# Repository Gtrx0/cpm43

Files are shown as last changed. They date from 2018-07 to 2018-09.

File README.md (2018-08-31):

# CPM43
40% Mechanical keyboard PCB

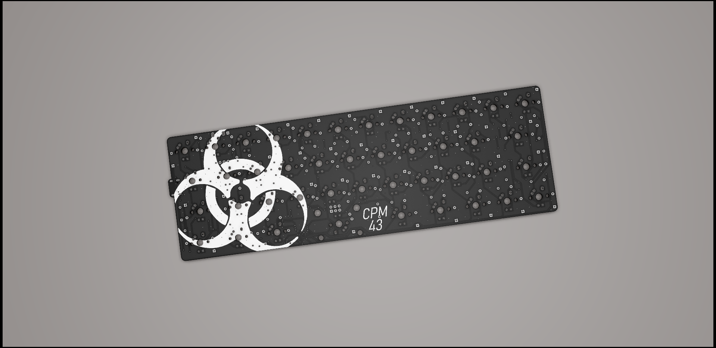
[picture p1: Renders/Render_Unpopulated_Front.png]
Frontside Render

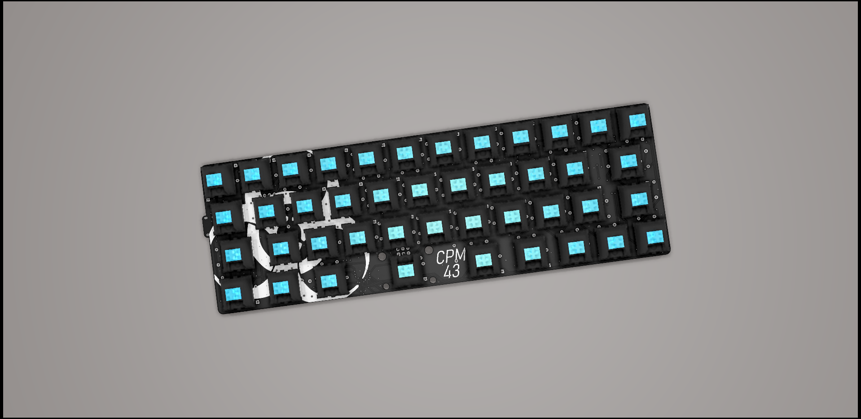
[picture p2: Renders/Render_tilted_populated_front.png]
Frontside Render

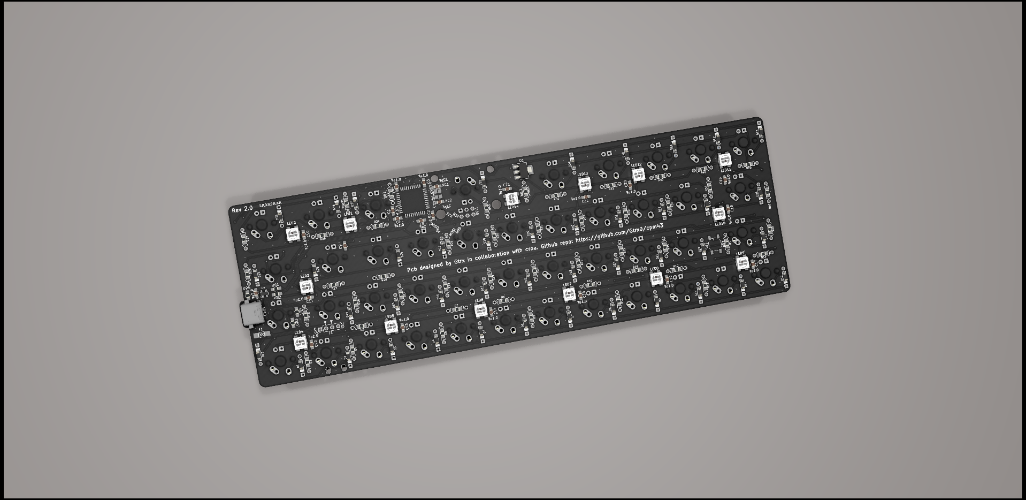
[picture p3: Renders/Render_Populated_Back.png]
Frontside Render

# [Layout](http://www.keyboard-layout-editor.com/#/gists/e3d0a9a1f7fb6537a82bb3f0c82ddf35)

## Features
* In-switch LED support.
* Individually addressible RGB underglow provided by 14 separate WS2812B LEDs.
* USB Type-C connector on the left side.
* Compatible with Cherry MX and ALPS switches. 
* Integrated 16MHz Atmega32u4 microcontroller for better QMK compatibility.
* USB ESD protection circuit.
* ICSP programming header just in case you try something a bit too extreme and need to unbrick it.
* 0805 SMD and through hole Diode/resistor compatibility for ease of assembly.
* USB breakout for extra redundency.

## Warning
KiCad 5 or above is needed to open this project. KiCad 4 or below won't work.

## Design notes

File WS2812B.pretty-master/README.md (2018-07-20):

WS2812B.pretty
==============

LAYOUT FILES: KiCad footprints for WS2812B LEDs (and pin-compatible ones).

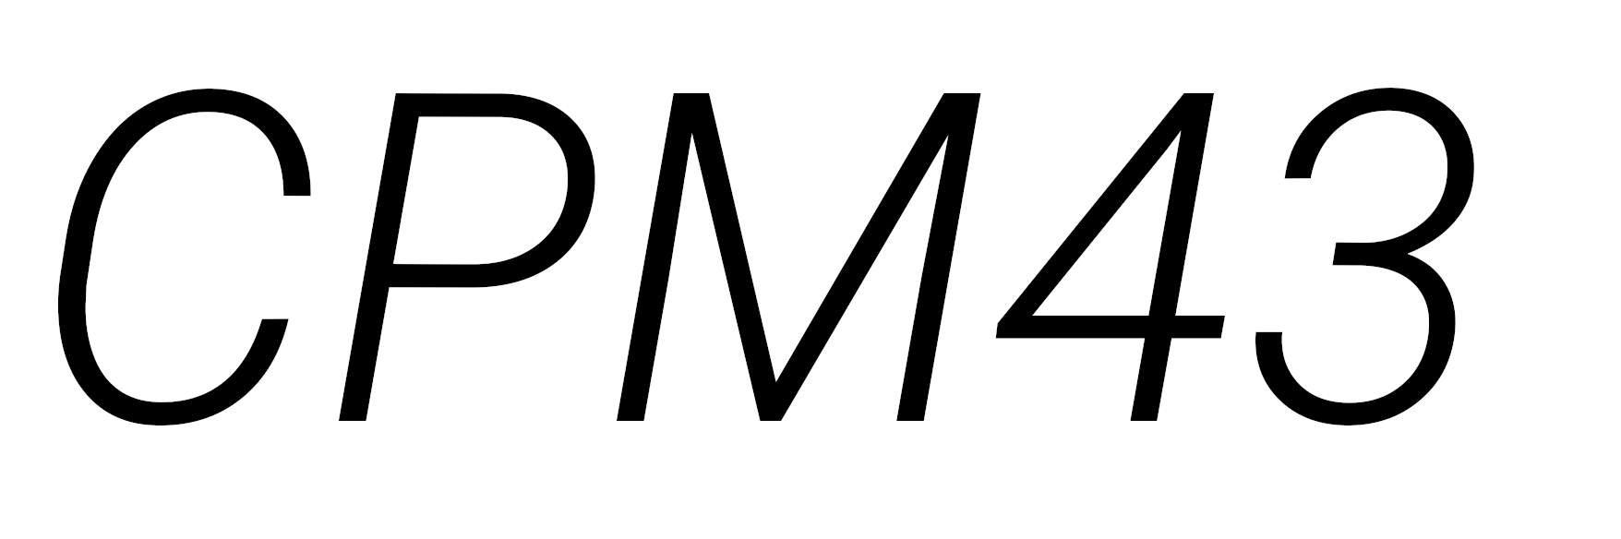
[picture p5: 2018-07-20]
CPM title/CPMtitle2.png

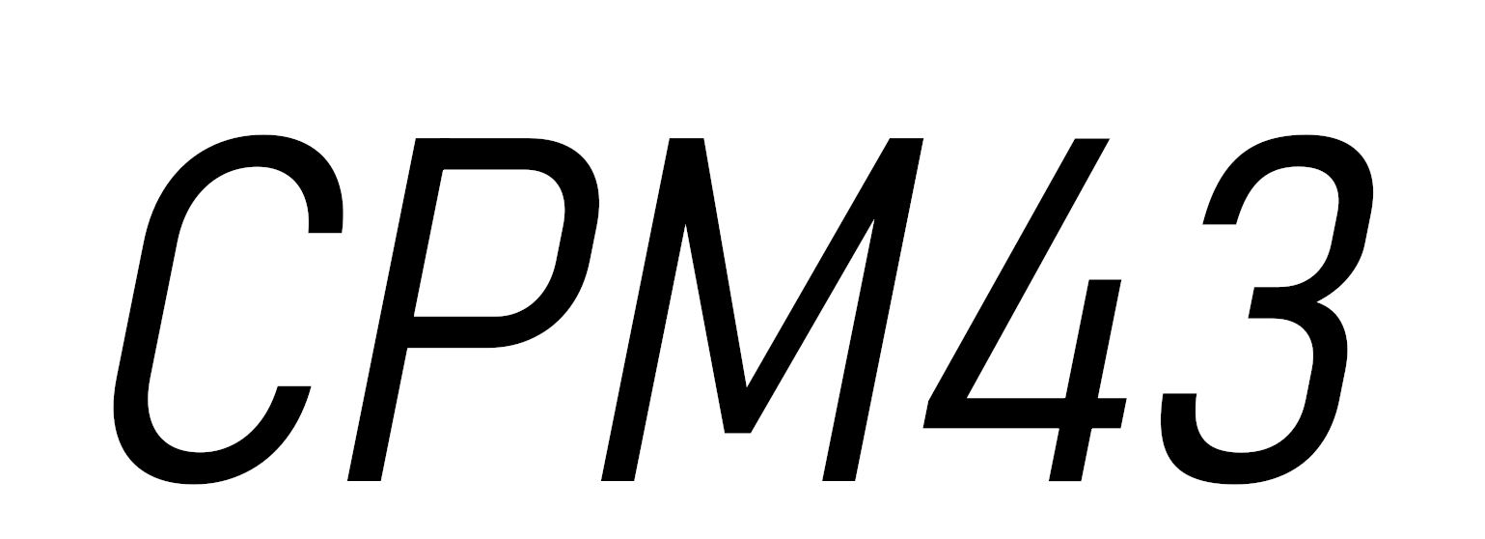
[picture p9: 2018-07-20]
CPM title/CPM4.3.png

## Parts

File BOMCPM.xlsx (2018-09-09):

Components for 1 board:
Item | Qty | Reference(s) | Value | Part name | Footprint | SMD | THT
1 | 20 | C2, C3, C4, C5, C8, C9, C10, C11, C12, C13, C14, C15, C16, C17, C18, C19, C20, C21, C22, | 0.1uF | Ceramic Capacitor | 0805_SMD | https://lcsc.com/product-detail/Multilayer-Ceramic-Capacitors-MLCC-SMD-SMT_100nF-104-5-50V_C29926.html
2 | 2 | C1, C7 | 4.7uF | Ceramic Capacitor | 0805_SMD | https://lcsc.com/product-detail/Multilayer-Ceramic-Capacitors-MLCC-SMD-SMT_SAMSUNG_CL21A475KOFNNNE_4-7uF-475-10-16V_C1746.html
3 | 1 | C6 | 1uF | Ceramic Capacitor | 0805_SMD | https://lcsc.com/product-detail/Multilayer-Ceramic-Capacitors-MLCC-SMD-SMT_KEMET_C0805C105J4RAC7800_KEMET-C0805C105J4RAC7800_C141130.html
4 | 43 | D1-43 | - | Zener Diode | THT, 0805_SMD, SOT123_SMD | https://lcsc.com/product-detail/Switching-Diode_DIODES_1N4148W-7-F_1N4148W-7-F_C83528.html | https://lcsc.com/product-detail/Switching-Diode_1N4148_C179504.html
5 | 1 | F1 | 500mA Hold | Polyfuse | 1206_SMD | https://lcsc.com/product-detail/Surface-Mount-Fuses_Littelfuse_RF1347-000_Littelfuse-RF1347-000_C207193.html
6 | 14 | LED1-14 | - | WS2812B rgb led | WS2812B_SMD | https://lcsc.com/product-detail/Light-Emitting-Diodes-LED_5050-RGBIntegrated-Light-4Pin_C114586.html
7 | 1 | NPNR1 | 1.5k ohm | Resistor | THT, 0805_SMD | https://lcsc.com/product-detail/Chip-Resistor-Surface-Mount-UniOhm_Uniroyal-Elec-0805W8J0152T5E_C26015.html | https://lcsc.com/product-detail/Metal-Film-Resistor-TH_TA-I-Tech-RN16T21501F_C172500.html
8 | 1 | Q1 | - | NPN transistor | SOT223_SMD | https://lcsc.com/product-detail/Others_Nexperia_BCP56-10-115_Nexperia-BCP56-10-115_C192156.html
9 | 2 | R1, R2 | 10k ohm | Resistor | THT, 0805_SMD | https://lcsc.com/product-detail/Chip-Resistor-Surface-Mount-UniOhm_Uniroyal-Elec-0805W8F1002T5E_C17414.html | https://lcsc.com/product-detail/Metal-Film-Resistor-TH_10KR-1002-1_C58673.html
10 | 43 | R3, R4, R5, R6, R7, R8, R9, R10, R11, R12, R13, R14, R15, R16, R17, R18, R19, R20, R21, R22, R23, R24, R25, R26, R27, R28, R29, R30, R31, R32, R33, R34, R35, R36, R37, R38, R39, R40, R41, R42, R43, R44, R45 | 576-1k will work depending on led forward voltage | Resistor | THT, 0805_SMD | https://lcsc.com/product-detail/Chip-Resistor-Surface-Mount-UniOhm_Uniroyal-Elec-0805W8F5760T5E_C17761.html | https://lcsc.com/product-detail/Metal-Film-Resistor-TH_470R-4700-1_C58592.html
11 | 1 | RGBR1 | 470 to 1k ohm | Resistor | THT, 0805_SMD | https://lcsc.com/product-detail/Chip-Resistor-Surface-Mount-UniOhm_Uniroyal-Elec-0805W8F5760T5E_C17761.html | https://lcsc.com/product-detail/Metal-Film-Resistor-TH_470R-4700-1_C58592.html
12 | 1 | SPI1 | - | 2x3 tht connector | 2x3 THT, 1.27mm pin pitch (ONLY SOLDER IN WHEN YOU NEED ISP FLASHING) | https://lcsc.com/product-detail/Male-Header_Shenzhen-Cancome-Headers-Pins-2-3P-2-54mm-Straight-line_C124384.html
13 | 1 | SW1 | - | Tact switch | CandK_6x6mm_Tactile_SMD | https://lcsc.com/product-detail/Tactile-Switches_K2-1187SQ-C4SW_C108649.html
14 | 1 | U1 | - | ATmega32U4 QFP44 | QFP44_SMD | https://lcsc.com/product-detail/ATMEL-AVR_ATMEL_ATMEGA32U4-AU_ATMEGA32U4-AU_C44854.html
15 | 1 | U2 | - | PRTR5V0U2X | SOT143B_SMD | https://lcsc.com/product-detail/Diodes-ESD_Nexperia_PRTR5V0U2X-215_PRTR5V0U2X-215_C12333.html
16 | 2 | UR1, UR2 | 22 ohm | Resistor | THT, 0805_SMD | https://lcsc.com/product-detail/High-Precision-Low-TCR-SMD-Resistors_22R-1-25PPM_C65068.html | https://lcsc.com/product-detail/Metal-Film-Resistor-TH_22R-22R0-1_C119142.html
17 | 2 | UR3, UR4 | 5.1k ohm | Resistor | THT, 0805_SMD | https://lcsc.com/product-detail/Chip-Resistor-Surface-Mount-UniOhm_Uniroyal-Elec-0805W8F5101T5E_C27834.html | https://lcsc.com/product-detail/Metal-Film-Resistor-TH_YAGEO-MFR-12FTE52-5K1_C172911.html
18 | 1 | UR5 | 1M ohm | Resistor | THT, 0805_SMD | https://lcsc.com/product-detail/Chip-Resistor-Surface-Mount-UniOhm_Uniroyal-Elec-0805W8F1004T5E_C17514.html | https://lcsc.com/product-detail/Metal-Film-Resistor-TH_YAGEO-MFR-12FTE52-1M_C172896.html
19 | 1 | USB1 | - | HRO-TYPE-C-31-M-12 | HRO-TYPE-C-31-M-12_SMD | https://lcsc.com/product-detail/USB-Type-C_TYPE-C-31-M-12-Female-16P-SMD_C165948.html
20 | 1 | X1 | 16mhz, 20ppm, 18pF | Crystal occilator | 3225-4pin_3.2x2.5mm_SMD | https://lcsc.com/product-detail/SMD-Crystals_YSX321SL-16MHZ-18PF-10PPM-40-85_C70562.html
21 | 2 | XC1, XC2 | 22pF | Ceramic Capacitor | 0805_SMD | https://lcsc.com/product-detail/Multilayer-Ceramic-Capacitors-MLCC-SMD-SMT_22pF-220-1-50V_C190088.html

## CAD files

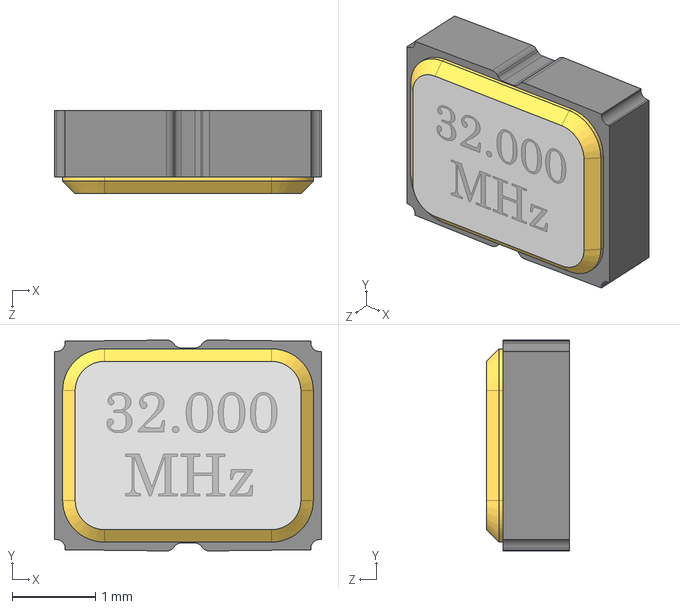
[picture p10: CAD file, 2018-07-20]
3D/OSC3225.STEP
3.20 x 2.53 x 1.00 mm

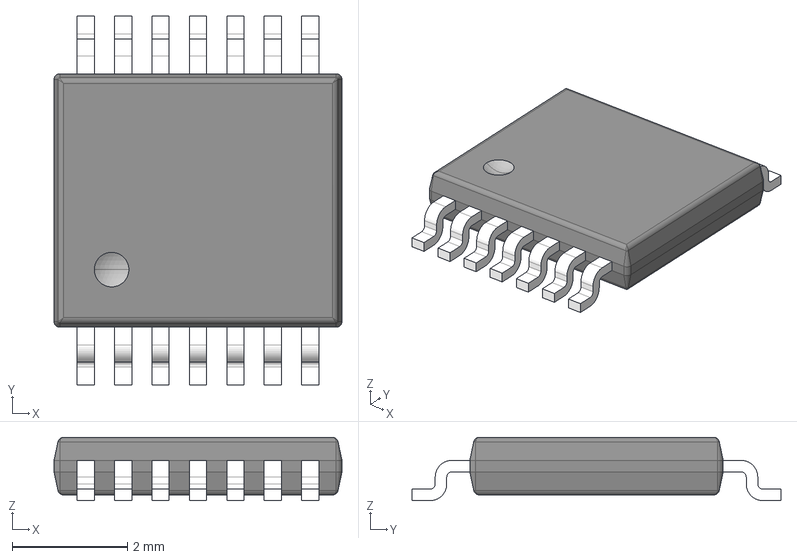
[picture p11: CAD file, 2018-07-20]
Nexperia/Nexperia/3D/SOT402 MO153 TSSOP14-1.step
5.00 x 6.40 x 1.10 mm

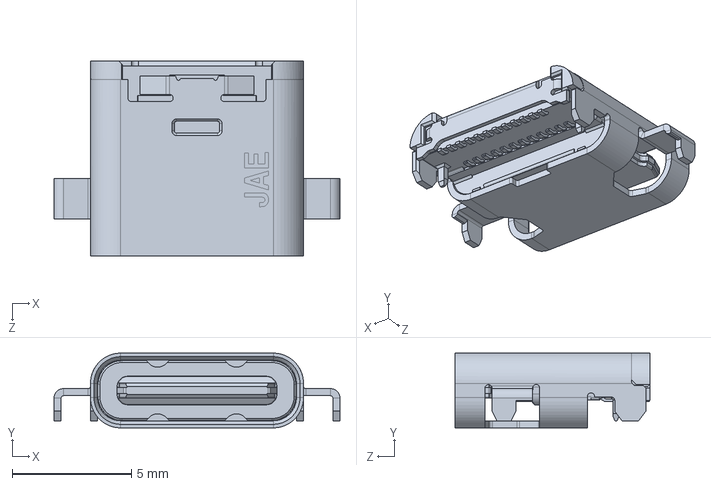
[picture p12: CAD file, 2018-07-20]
3D/K3D-DX07B024JJ1-V1_JAE_Proprietary.STEP
12.0 x 3.14 x 8.17 mm

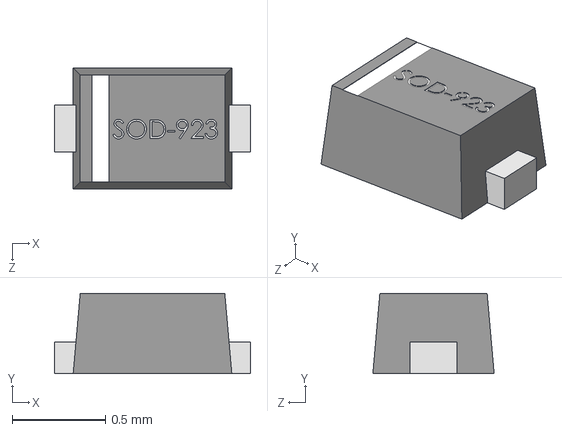
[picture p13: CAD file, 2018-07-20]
Nexperia/Nexperia/3D/SOD923.step
1.05 x 0.43 x 0.65 mm

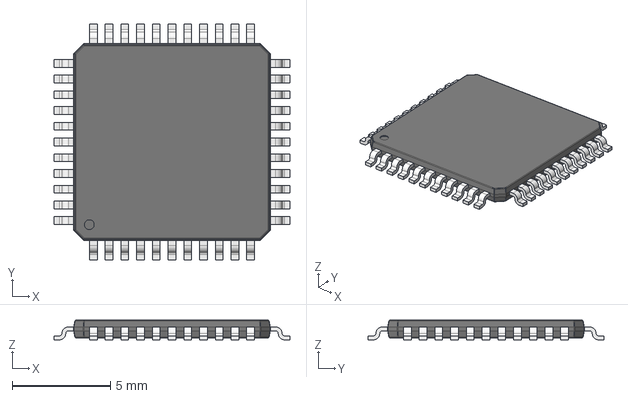
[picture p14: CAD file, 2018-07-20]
3D/qfp80p-10mmx10mm-44 v1.step
12.0 x 12.0 x 1.00 mm
icbody
pin0.25mm x 44

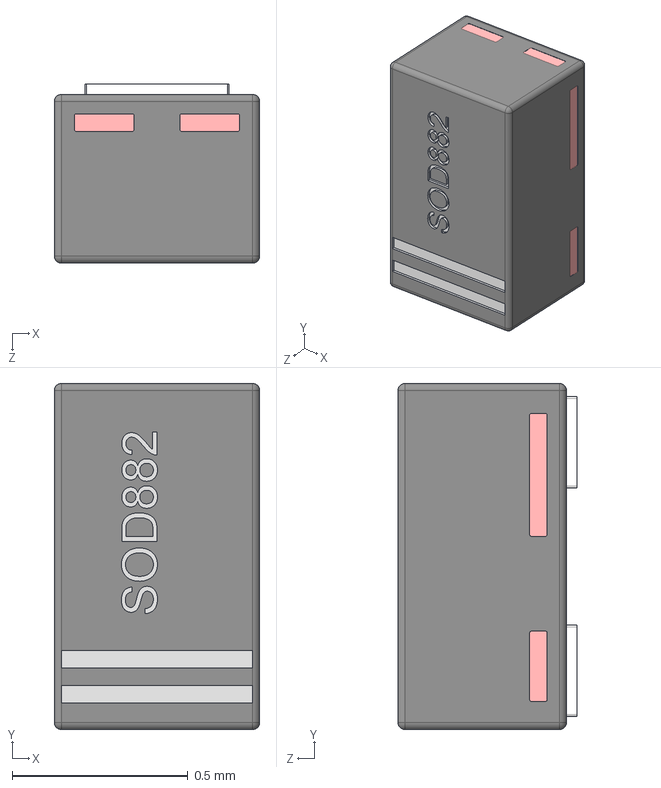
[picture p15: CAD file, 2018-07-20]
Nexperia/Nexperia/3D/SOD882-1.step
0.585 x 0.985 x 0.51 mm

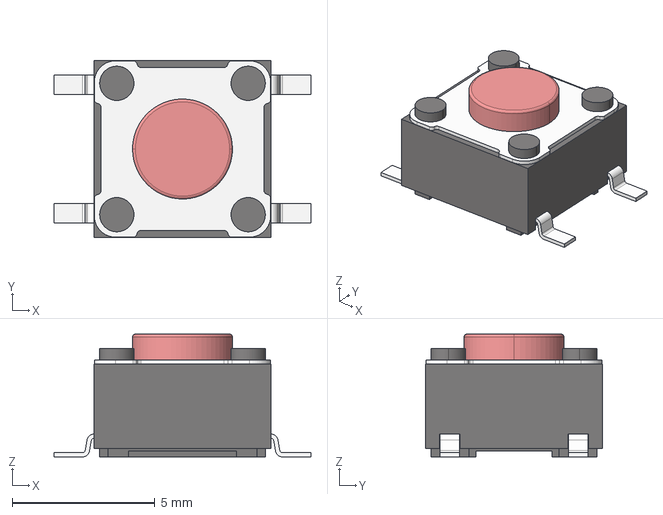
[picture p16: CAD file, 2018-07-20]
3D/Tact Switch SMD 6x6mm.stp
9.00 x 6.20 x 4.30 mm

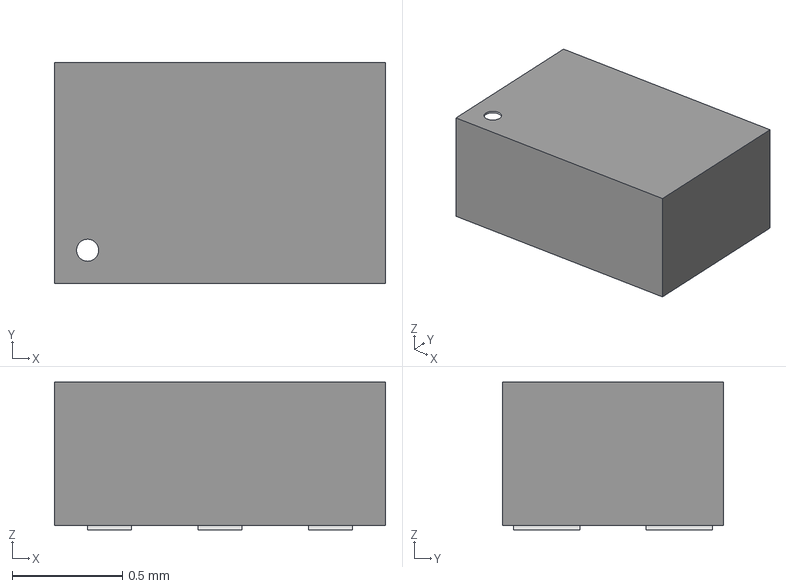
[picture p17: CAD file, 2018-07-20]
Nexperia/Nexperia/3D/MO-252D-UAAD.step
1.50 x 1.00 x 0.67 mm

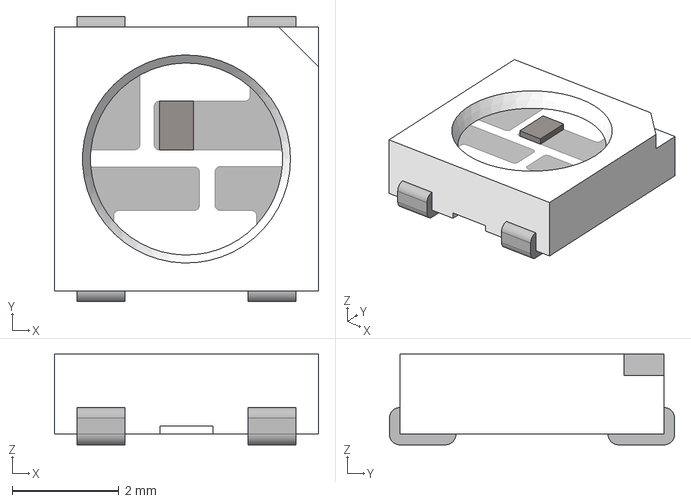
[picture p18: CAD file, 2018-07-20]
3D/WS2812_RGB_LED_updated.stp
4.95 x 5.35 x 1.70 mm

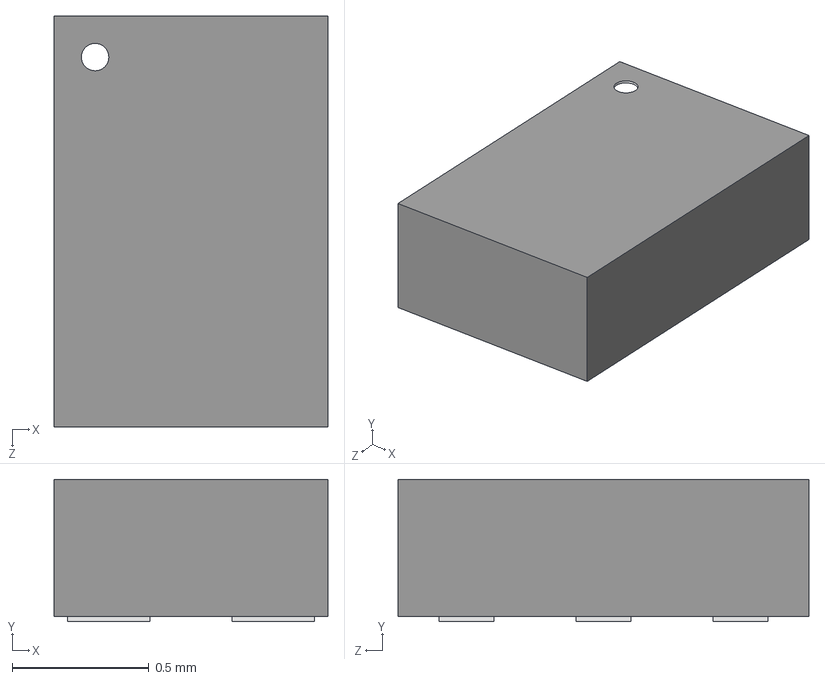
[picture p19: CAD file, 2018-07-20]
Nexperia/Nexperia/3D/MO-252DX1510D-6pin.STEP
1.00 x 0.52 x 1.50 mm

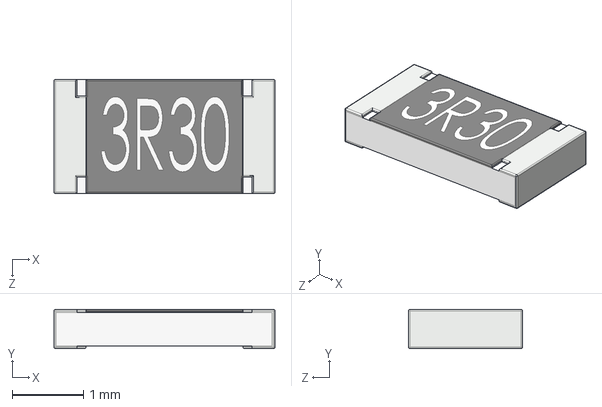
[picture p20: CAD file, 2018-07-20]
3D/res1206r.STEP
3.10 x 0.551 x 1.60 mm

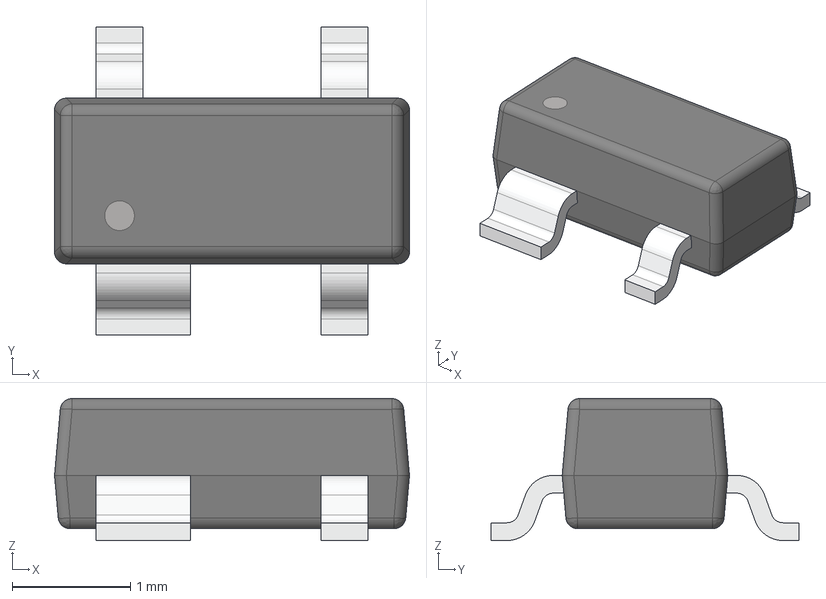
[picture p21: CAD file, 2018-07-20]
3D/TO-253AA.stp
3.00 x 2.60 x 1.20 mm

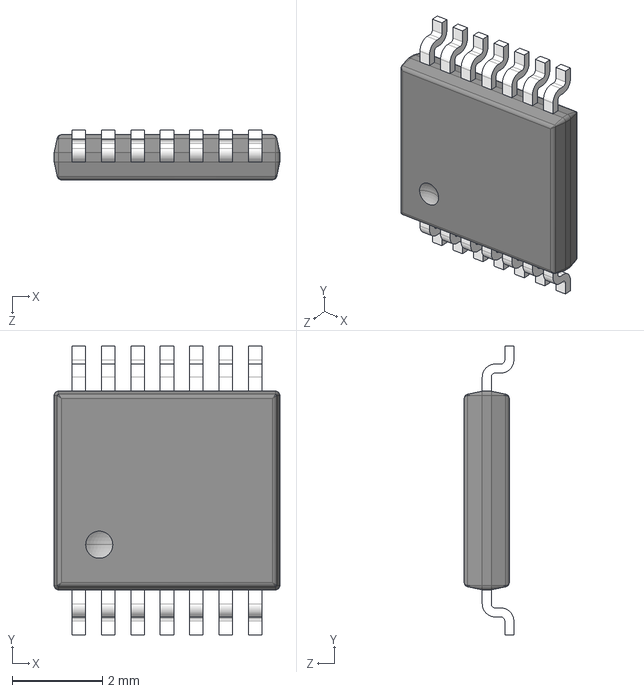
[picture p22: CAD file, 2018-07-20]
Nexperia/Nexperia/3D/SOT402 MO153 TSSOP14-1_orig.step
5.00 x 6.40 x 1.10 mm

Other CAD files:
Nexperia/Nexperia/3D/User Library-MO-252DU1510D (UAAD).STEP
Nexperia/Nexperia/3D/MO-252DU1510D (UAAD)-4pin.STEP
Nexperia/Nexperia/3D/SC-70-6.stp

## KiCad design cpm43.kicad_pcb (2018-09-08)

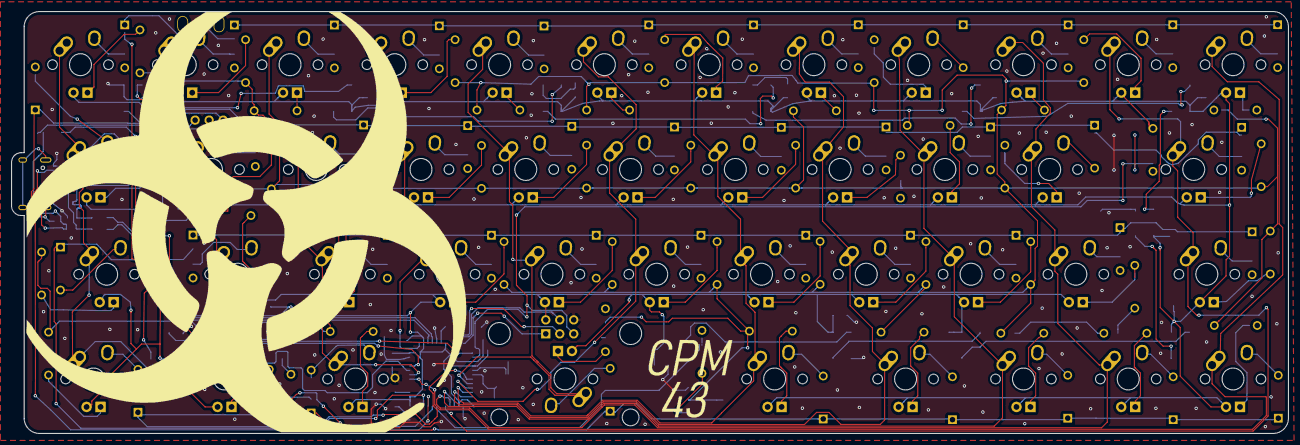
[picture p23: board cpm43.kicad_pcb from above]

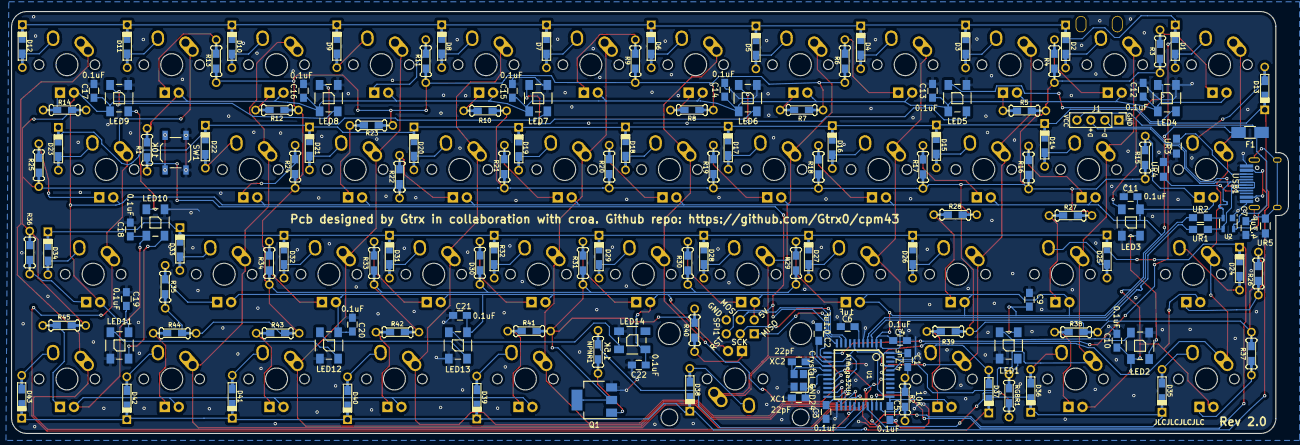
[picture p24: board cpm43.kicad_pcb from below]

Board: 2 copper layers, 232.2 x 76.7 mm, 186 parts (50 on the bottom side), 138 nets.

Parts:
C1: 0.1uf; C_0805_HandSoldering
C2, C3, C5, C9, C10, C11, C12, C13, C14, C15, C16, C17, C18, C19, C20, C21, C22: 0.1uF; C_0805_HandSoldering
C4, C7: 4.7uF; C_0805_HandSoldering
C6: 1uF; C_0805_HandSoldering
D1, D2, D3, D4, D5, D6, D7, D8, D9, D10, D11, D12, D13, D14, D15, D16, D17, D18, D19, D20, D21, D22, D23, D24, D25, D26, D27, D28, D29, D30, D31, D32, D33, D34, D35, D36, D37, D38, D39, D40, D41, D42, D43: D; Diode-Hybrid-Back
F1: 500mA Hold; Fuse_SMD1206_HandSoldering
J1: Conn_01x04; Pin_Header_Straight_1x04_Pitch2.54mm
LED1, LED2, LED3, LED4, LED5, LED6, LED7, LED8, LED9, LED10, LED11, LED12, LED13, LED14: WS2812B
MX1, MX2, MX3, MX4, MX5, MX6, MX7, MX8, MX9, MX10, MX11, MX12, MX14, MX15, MX16, MX17, MX18, MX19, MX20, MX21, MX22, MX25, MX26, MX27, MX28, MX29, MX30, MX31, MX32, MX33, MX41, MX42, MX43: MX-1U
MX13: MX-1.25U; MX-1.25U-FLIPPED
MX23: MX-1.75U
MX24: MX-1.5U
MX34: MX-1.25U; MX-1.5U
MX35, MX36, MX37, MX39, MX40: MX-1.25U
MX38: MX-2.75U
NPNR1: 1.5k; Resistor-Hybrid-Back
P?: CONN_1; PIN_1
P?#2: CONN_1; PIN_1
Q1: Q_NPN_BCE; SOT-223-3_TabPin2
R1, R2: 10k; Resistor-Hybrid-Back
R3, R4, R5, R6, R7, R8, R9, R10, R11, R12, R13, R14, R15, R16, R17, R18, R19, R20, R21, R22, R23, R24, R25, R26, R27, R28, R29, R30, R31, R32, R33, R34, R35, R36, R37, R38, R39, R40, R41, R42, R43, R44, R45: 470; Resistor-Hybrid-Back
RGBR1: 470; Resistor-Hybrid-Back
SPI1: 2x3 SPI; Pin_Header_Straight_2x03_Pitch2.54mm
SW1: SW_PUSH; SW_SPST_TL3342
U1: ATmega32U4; QFP44
U2: PRTR5V0U2X; SOT143B
UR1, UR2: 22; R_0805_HandSoldering
UR3, UR4: 5.1k; R_0805_HandSoldering
UR5: 1M; R_0805_HandSoldering
USB1: HRO-TYPE-C-31-M-12; HRO-TYPE-C-31-M-12-HandSoldering
X1: Crystal_GND24; Crystal_SMD_3225-4pin_3.2x2.5mm
XC1, XC2: 22pF; C_0805_HandSoldering

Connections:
+5V: C1.1, C2.1, C3.1, C4.1, C5.1, C9.1, C10.1, C11.1, C12.1, C13.1, C14.1, C15.1, C16.1, C17.1, C18.1, C19.1, C20.1, C21.1, C22.1, F1.2, LED1.1, LED2.1, LED3.1, LED4.1, LED5.1, LED6.1, LED7.1, LED8.1, LED9.1, LED10.1, LED11.1, LED12.1, LED13.1, LED14.1, MX1.3, MX2.3, MX3.3, MX4.3, MX5.3, MX6.3, MX7.3, MX8.3, MX9.3, MX10.3, MX11.3, MX12.3, MX13.3, MX14.3, MX15.3, MX16.3, MX17.3, MX18.3, MX19.3, MX20.3, MX21.3, MX22.3, MX23.3, MX24.3, MX25.3, MX26.3, MX27.3, MX28.3, MX29.3, MX30.3, MX31.3, MX32.3, MX33.3, MX34.3, MX35.3, MX36.3, MX37.3, MX38.3, MX39.3, MX40.3, MX41.3, MX42.3, MX43.3, R1.1, SPI1.2, U1.2, U1.7, U1.14, U1.24, U1.34, U1.44
COL0: MX1.1, MX13.1, MX24.1, MX35.1, U1.41
COL1: MX2.1, MX14.1, MX25.1, MX36.1, U1.40
COL2: MX3.1, MX15.1, MX26.1, MX37.1, U1.39
COL3: MX4.1, MX16.1, MX27.1, U1.1
COL4: MX5.1, MX17.1, MX28.1, MX38.1, U1.19
COL5: MX6.1, MX18.1, MX29.1, U1.20
COL6: MX7.1, MX19.1, MX30.1, MX39.1, U1.21
COL7: MX8.1, MX20.1, MX31.1, MX40.1, U1.22
COL8: MX9.1, MX21.1, MX32.1, MX41.1, U1.25
COL9: MX10.1, MX22.1, MX33.1, MX42.1, U1.26
COL10: MX11.1, MX23.1, MX34.1, U1.27
COL11: MX12.1, MX43.1, U1.38
D+: U1.4, UR2.1
D-: U1.3, UR1.2
GND: C1.2, C2.2, C3.2, C4.2, C5.2, C6.1, C7.1, C9.2, C10.2, C11.2, C12.2, C13.2, C14.2, C15.2, C16.2, C17.2, C18.2, C19.2, C20.2, C21.2, C22.2, J1.1, LED1.3, LED2.3, LED3.3, LED4.3, LED5.3, LED6.3, LED7.3, LED8.3, LED9.3, LED10.3, LED11.3, LED12.3, LED13.3, LED14.3, Q1.3, R2.2, SPI1.6, SW1.1, U1.5, U1.15, U1.23, U1.35, U1.43, U2.1, UR3.1, UR4.2, UR5.1, USB1.1, USB1.12, X1.2, XC1.2, XC2.2
LEDGND: Q1.2, R3.1, R4.1, R5.1, R6.1, R7.1, R8.1, R9.1, R10.1, R11.1, R12.1, R13.1, R14.1, R15.1, R16.1, R17.1, R18.1, R19.1, R20.1, R21.1, R22.1, R23.1, R24.1, R25.1, R26.1, R27.1, R28.1, R29.1, R30.1, R31.1, R32.1, R33.1, R34.1, R35.1, R36.1, R37.1, R38.1, R39.1, R40.1, R41.1, R42.1, R43.1, R44.1, R45.1
LEDPWM: NPNR1.1, U1.29
MISO: SPI1.1, U1.11
MOSI: SPI1.4, U1.10
unnamed: C6.2, U1.6
unnamed: C7.2, UR5.2, USB1.13
unnamed: D1.2, MX1.2
unnamed: D2.2, MX2.2
unnamed: D3.2, MX3.2
unnamed: D4.2, MX4.2
unnamed: D5.2, MX5.2
unnamed: D6.2, MX6.2
unnamed: D7.2, MX7.2
unnamed: D8.2, MX8.2
unnamed: D9.2, MX9.2
unnamed: D10.2, MX10.2
unnamed: D11.2, MX11.2
unnamed: D12.2, MX12.2
unnamed: D13.2, MX13.2
unnamed: D14.2, MX14.2
unnamed: D15.2, MX15.2
unnamed: D16.2, MX16.2
unnamed: D17.2, MX17.2
unnamed: D18.2, MX18.2
unnamed: D19.2, MX19.2
unnamed: D20.2, MX20.2
unnamed: D21.2, MX21.2
unnamed: D22.2, MX22.2
unnamed: D23.2, MX23.2
unnamed: D24.2, MX24.2
unnamed: D25.2, MX25.2
unnamed: D26.2, MX26.2
unnamed: D27.2, MX27.2
unnamed: D28.2, MX28.2
unnamed: D29.2, MX29.2
unnamed: D30.2, MX30.2
unnamed: D31.2, MX31.2
unnamed: D32.2, MX32.2
unnamed: D33.2, MX33.2
unnamed: D34.2, MX34.2
unnamed: D35.2, MX35.2
unnamed: D36.2, MX36.2
unnamed: D37.2, MX37.2
unnamed: D38.2, MX38.2
unnamed: D39.2, MX39.2
unnamed: D40.2, MX40.2
unnamed: D41.2, MX41.2
unnamed: D42.2, MX42.2
unnamed: D43.2, MX43.2
unnamed: J1.2, U2.3, UR1.1, USB1.5, USB1.7
unnamed: J1.3, U2.2, UR2.2, USB1.6, USB1.8
unnamed: LED1.2, LED2.4
unnamed: LED1.4, RGBR1.2
unnamed: LED2.2, LED3.4
unnamed: LED3.2, LED4.4
unnamed: LED4.2, LED5.4
unnamed: LED5.2, LED6.4
unnamed: LED6.2, LED7.4
unnamed: LED7.2, LED8.4
unnamed: LED8.2, LED9.4
unnamed: LED10.2, LED11.4
unnamed: LED9.2, LED10.4
unnamed: LED11.2, LED12.4
unnamed: LED12.2, LED13.4
unnamed: LED13.2, LED14.4
unnamed: MX1.4, R3.2
unnamed: MX2.4, R4.2
unnamed: MX3.4, R5.2
unnamed: MX4.4, R6.2
unnamed: MX5.4, R7.2
unnamed: MX6.4, R8.2
unnamed: MX7.4, R9.2
unnamed: MX8.4, R10.2
unnamed: MX9.4, R11.2
unnamed: MX10.4, R12.2
unnamed: MX11.4, R13.2
unnamed: MX12.4, R14.2
unnamed: MX13.4, R15.2
unnamed: MX14.4, R16.2
unnamed: MX15.4, R17.2
unnamed: MX16.4, R18.2
unnamed: MX17.4, R19.2
unnamed: MX18.4, R20.2
unnamed: MX19.4, R21.2
unnamed: MX20.4, R22.2
unnamed: MX21.4, R23.2
unnamed: MX22.4, R24.2
unnamed: MX23.4, R25.2
unnamed: MX24.4, R26.2
unnamed: MX25.4, R27.2
unnamed: MX26.4, R28.2
unnamed: MX27.4, R29.2
unnamed: MX28.4, R30.2
unnamed: MX29.4, R31.2
unnamed: MX30.4, R32.2
unnamed: MX31.4, R33.2
unnamed: MX32.4, R34.2
unnamed: MX33.4, R35.2
unnamed: MX34.4, R36.2
unnamed: MX35.4, R37.2
unnamed: MX36.4, R38.2
unnamed: MX37.4, R39.2
unnamed: MX38.4, R40.2
unnamed: MX39.4, R41.2
unnamed: MX40.4, R42.2
unnamed: MX41.4, R43.2
unnamed: MX42.4, R44.2
unnamed: MX43.4, R45.2
unnamed: NPNR1.2, Q1.1
unnamed: R2.1, U1.33
unnamed: U1.16, X1.3, XC2.1
unnamed: U1.17, X1.1, XC1.1
unnamed: UR3.2, USB1.10
unnamed: UR4.1, USB1.4
RGBIN: RGBR1.1, U1.30
ROW0: D1.1, D2.1, D3.1, D4.1, D5.1, D6.1, D7.1, D8.1, D9.1, D10.1, D11.1, D12.1, U1.12
ROW1: D13.1, D14.1, D15.1, D16.1, D17.1, D18.1, D19.1, D20.1, D21.1, D22.1, D23.1, U1.31
ROW2: D24.1, D25.1, D26.1, D27.1, D28.1, D29.1, D30.1, D31.1, D32.1, D33.1, D34.1, U1.32
ROW3: D35.1, D36.1, D37.1, D38.1, D39.1, D40.1, D41.1, D42.1, D43.1, U1.18
RST: R1.2, SPI1.5, SW1.2, U1.13
SCK: SPI1.3, U1.9
VCC: F1.1, J1.4, U2.4, USB1.2, USB1.11

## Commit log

2018-07-20 Kicad Project Files
    Designed in kicad 5. Wont work in kicad 4.
    [BOMCPM.csv, K3D-DX07B024JJ1-V1_JAE_Proprietary.STEP, MO-252D-UAAD.step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]
2018-07-20 Changed BOM and KiCad Files
    [BOMCPM.csv, BOMCPM.xlsx]
2018-07-20 Changed renders
    [cpm43.kicad_pcb]
2018-07-20 Silkscreen changed
    [cpm43.kicad_pcb]
2018-07-21 Edge cut changed, new renders
    [cpm43.kicad_pcb]
2018-07-21 Added Gerbers
    [cpm43-B.Cu.gbr, cpm43-B.Mask.gbr, cpm43-B.Paste.gbr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]
2018-07-23 Edge cuts have been changed
    [cpm43-B.Cu.gbr, cpm43-B.Mask.gbr, cpm43-B.Paste.gbr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]
2018-07-26 Changed BOM
    [BOMCPM.xlsx]
2018-07-26 BOM change
    [BOMCPM.xlsx]
2018-07-30 Hand soldering made not so hellish
    [BOMCPM.xlsx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]
2018-08-06 Changed decoupling cap value
    [BOMCPM.xlsx, cpm43.kicad_pcb, cpm43.sch]
2018-08-06 BOM changed
    [BOMCPM.xlsx]
2018-08-06 Fixed stab holes
    [cpm43-B.Cu.gbr, cpm43-B.Mask.gbr, cpm43-B.Paste.gbr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]
2018-08-09 Changed the switch so that it doesn't pull the reset line low forever
    [BOMCPM.xlsx]
2018-08-10 Bigger ICSP header
    [cpm43-B.Cu.gbr, cpm43-B.Mask.gbr, cpm43-B.Paste.gbr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]
2018-08-20 New gerbers and Silkscreen changes
    [cpm43-B.Cu.gbr, cpm43-B.Mask.gbr, cpm43-B.Paste.gbr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]
2018-08-30 Tact switch
    [cpm43-B.Cu.gbr, cpm43-B.Mask.gbr, cpm43-B.Paste.gbr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]
2018-08-30 Added usb breakout header
    [cpm43-B.Cu.gbr, cpm43-B.Mask.gbr, cpm43-B.Paste.gbr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]
2018-08-30 Mounting holes added
    [cpm43-B.Cu.gbr, cpm43-B.Mask.gbr, cpm43-B.Paste.gbr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]
2018-09-08 Fixed BS
    [cpm43-B.Cu.gbr, cpm43-B.Mask.gbr, cpm43-B.Paste.gbr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]
